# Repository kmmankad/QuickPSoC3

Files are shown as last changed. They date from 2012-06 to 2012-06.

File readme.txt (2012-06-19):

QuickPSoC3 V2
--------------

This is a quick-to-make development envrionment for the Cypress PSoC3 Platform.It is intended for students,hobbyists 
or anyone who wants a PSoC3 platform to play with,without paying a ton of money for it.

The goal is to have a home-etchable,cheap to put together,USB capable PSoC3 environment running with the least of hassle.

To know more about the PSoC3 platform - http://www.cypress.com/?id=2232

Board files are made in Eagle 6.2 LIGHT Edition.

This board:
-Uses the CY8C3866PVI-021/CY8C3246PVI-147 or any PSoC3 part in a 48pin SSOP package
-Has 26 GPIOs brought out to 0.1" headers.
-Uses the internal oscillator.
-Has a miniprog compatible header on the top right,for easy programming.
-Has a miniUSB connector,so can use a USB bootloader,for easier programming.
-Has extra long pads for soldering the PSoC,to make it easier for beginners to put together.
-The Mhz Crystal lines have not been routed out,but USB doesnt need an external crystal/resonator.
-Has smd passives of 0805 size,and the LEDs are 1206,but you can easily replace them with their through hole variants and get a fully through-hole board.
-Has an *Unregulated* voltage input which can be selected over USB's 5VDC.

I have successfully etched this using nothing but ordinary copier paper and a household iron,on some paper phenolic copper clad.So you dont require special techniques to etch it.

Updated 19-Jun-12:
Did away with some more components,to make this a quick-er board to put together.
Edited silkscreen at some places to make it more meaningful.

-kmmankad

http://kmmankad.blogspot.com

This work is licensed under a Creative Commons Attribution-ShareAlike 3.0 Unported License.

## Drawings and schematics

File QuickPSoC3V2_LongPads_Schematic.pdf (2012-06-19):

XRES - Reset Pushbutton | Mounting Holes

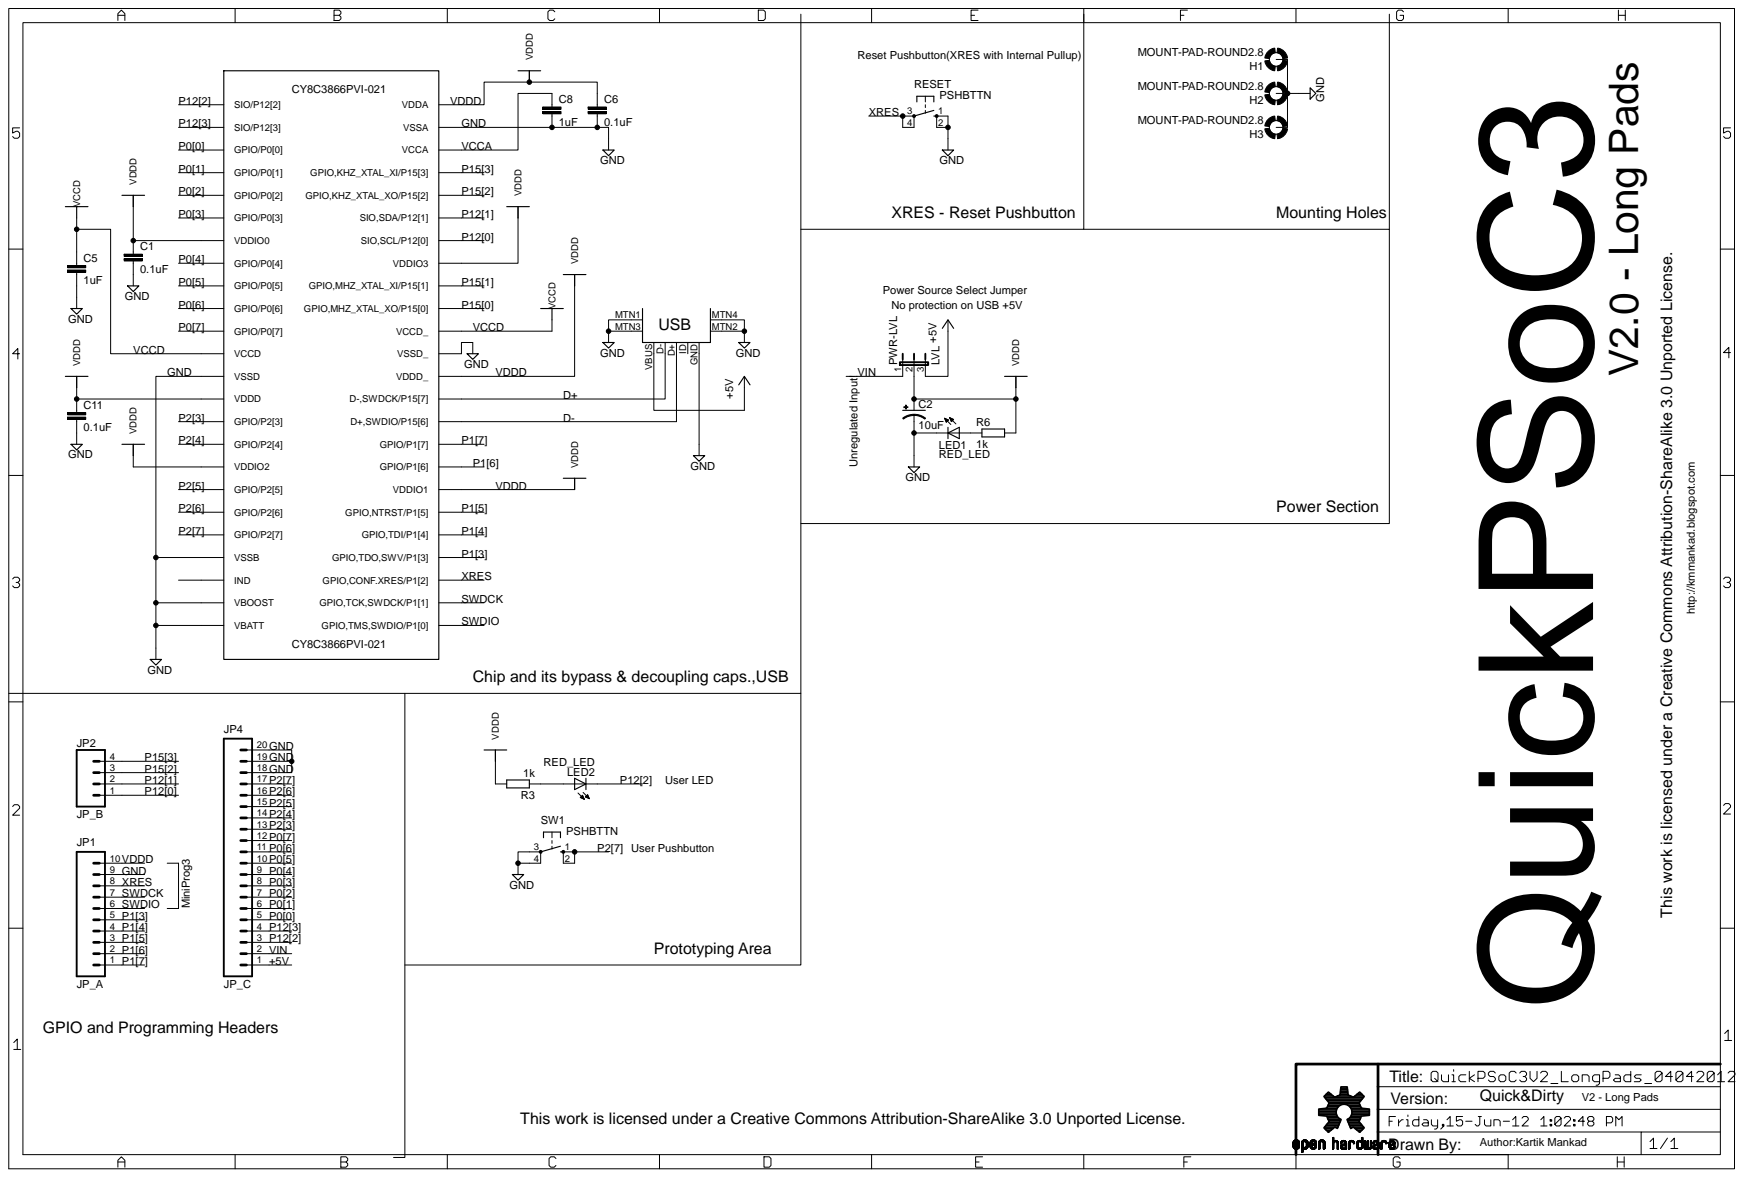
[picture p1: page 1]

Reset Pushbutton(XRES with Internal Pullup)

This work is licensed under a Creative Commons Attribution-ShareAlike 3.0 Unported License.

Power Source Select Jumper
No protection on USB +5V

http://kmmankad.blogspot.com

Chip and its bypass & decoupling caps.,USB

GPIO and Programming Headers

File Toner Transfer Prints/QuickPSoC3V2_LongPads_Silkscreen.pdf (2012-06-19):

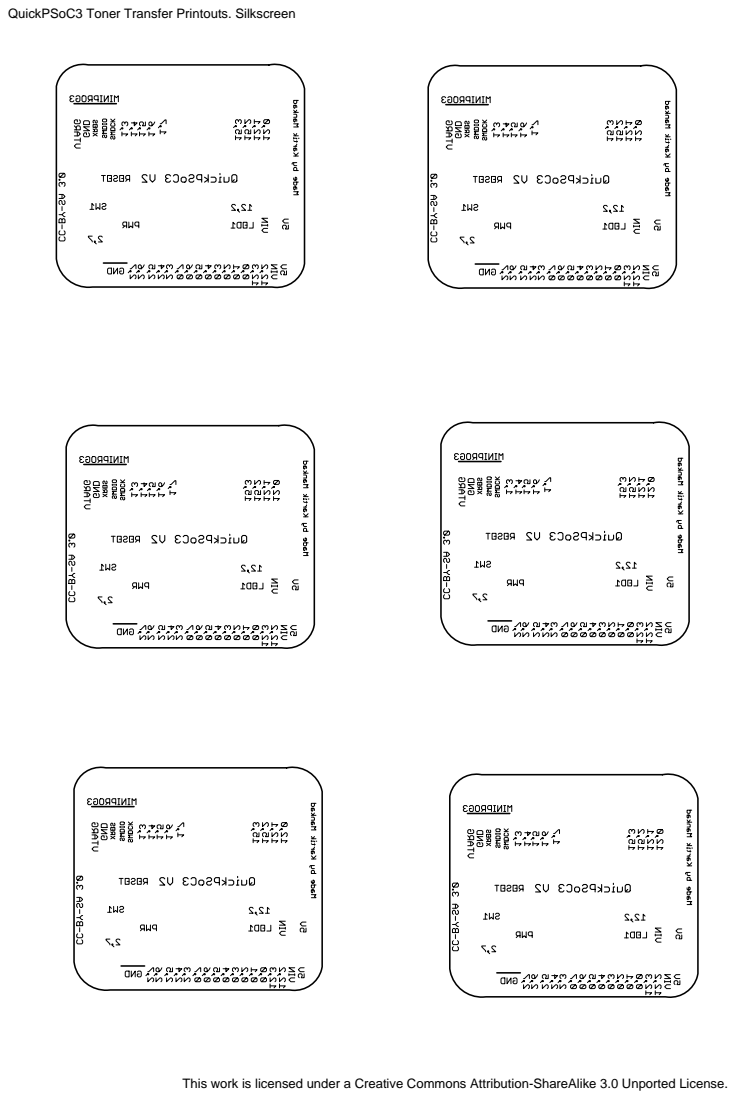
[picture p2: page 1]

QuickPSoC3 Toner Transfer Printouts. Silkscreen

This work is licensed under a Creative Commons Attribution-ShareAlike 3.0 Unported License.

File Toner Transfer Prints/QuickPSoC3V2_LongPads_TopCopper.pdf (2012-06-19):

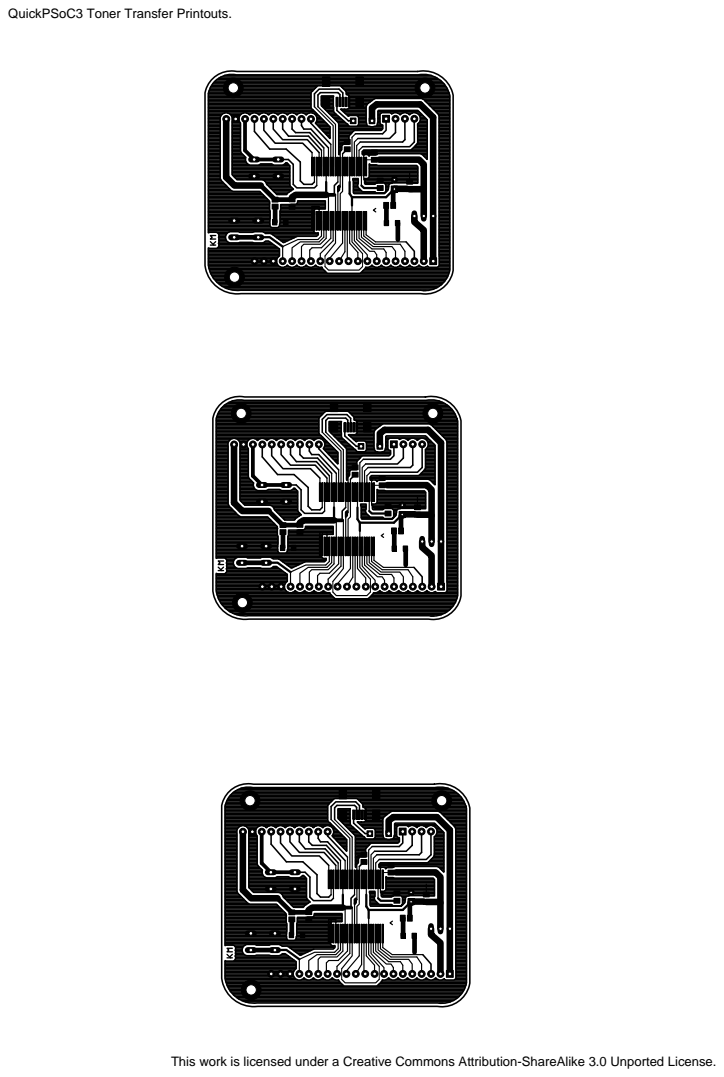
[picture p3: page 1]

QuickPSoC3 Toner Transfer Printouts.

This work is licensed under a Creative Commons Attribution-ShareAlike 3.0 Unported License.

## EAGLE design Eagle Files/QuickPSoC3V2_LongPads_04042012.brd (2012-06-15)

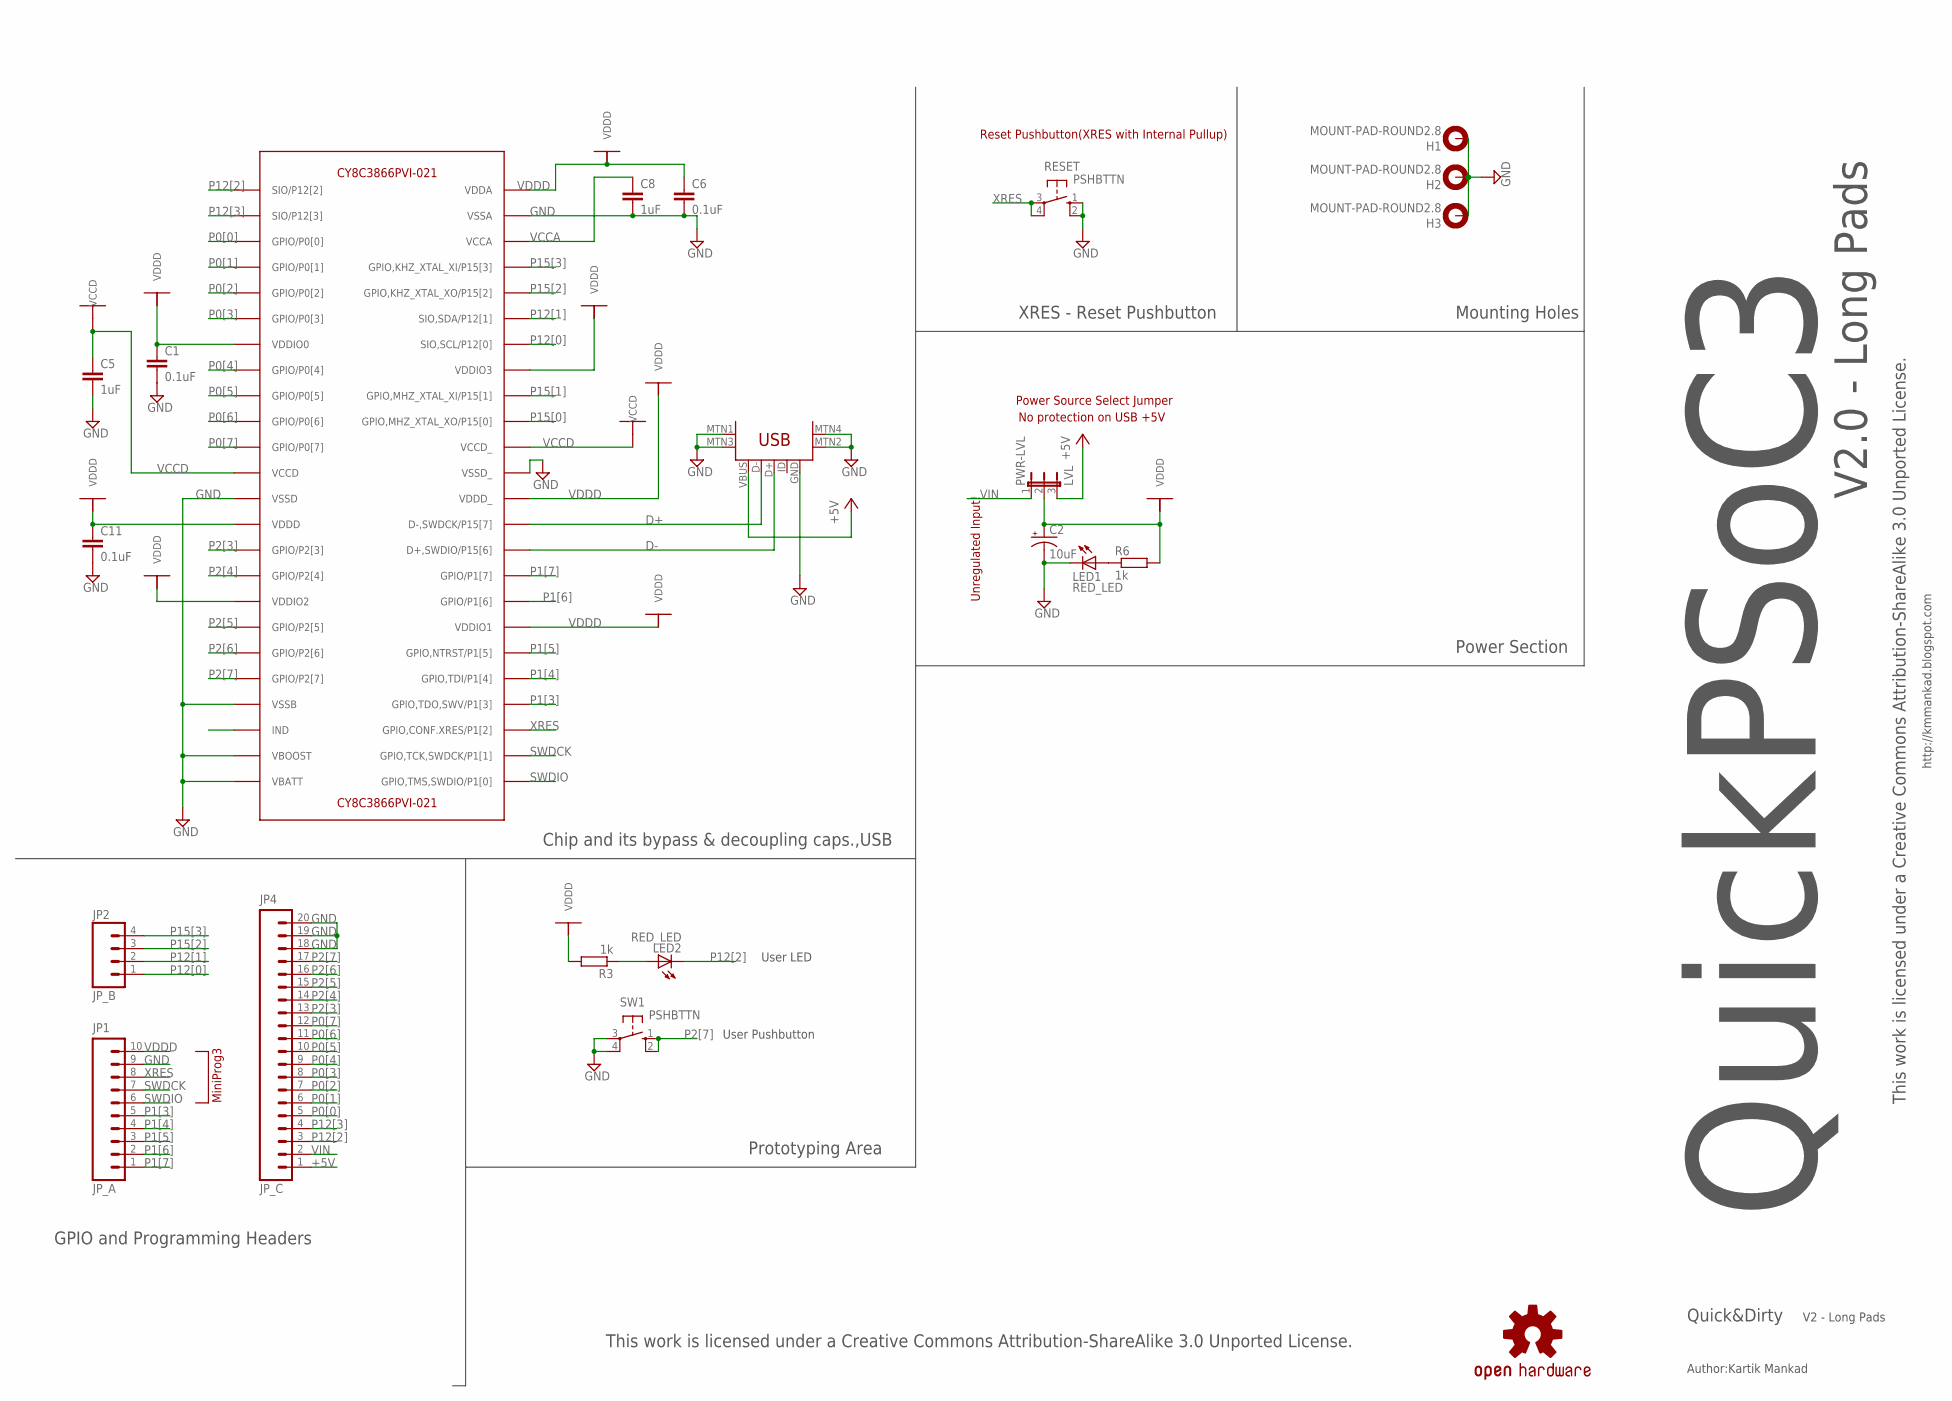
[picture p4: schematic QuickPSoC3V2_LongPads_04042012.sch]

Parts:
C1, C6, C11: 0.1uF; C0805K
C2: 10uF; CPOL-RADIAL-10UF-25V
C5, C8: 1uF; C0805K
H1, H2, H3: MOUNT-PAD-ROUND2.8; 2,8-PAD
JP1: JP_A; 1X10
JP2: JP_B; 1X04
JP4: JP_C; 1X20
LED1, LED2: RED_LED; LED-1206
PWR-LVL: LVL; JP2
R3, R6: 1k; M0805
RESET: PSHBTTN; B3F-10XX
SW1: PSHBTTN; B3F-10XX
U$1: CY8C3866PVI-021; SSOP48DL
U$2: OSHW-LOGOL; OSHW-LOGO-L
X1: USB-MINIB-5PIN; USB-MINIB

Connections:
+5V: JP4.1, PWR-LVL.3, X1.VBUS
D+: U$1.35 (D-,SWDCK/P15[7]), X1.D-
D-: U$1.34 (D+,SWDIO/P15[6]), X1.D+
GND: C1.2, C2.2 (-), C5.2, C6.2, C8.2, C11.2, H1.B2,8, H2.B2,8, H3.B2,8, JP1.9, JP4.18, JP4.19, JP4.20, LED1.C, RESET.1 (S), RESET.2 (S1), SW1.3, SW1.4 (P1), U$1.13 (VSSD), U$1.21 (VSSB), U$1.23 (VBOOST), U$1.24 (VBATT), U$1.37 (VSSD_), U$1.47 (VSSA), X1.GND, X1.MTN1 (MTN2), X1.MTN2 (MTN3), X1.MTN3 (MTN1), X1.MTN4
unnamed: LED1.A, R6.1
unnamed: LED2.A, R3.1
P0[0]: JP4.5, U$1.3 (GPIO/P0[0])
P0[1]: JP4.6, U$1.4 (GPIO/P0[1])
P0[2]: JP4.7, U$1.5 (GPIO/P0[2])
P0[3]: JP4.8, U$1.6 (GPIO/P0[3])
P0[4]: JP4.9, U$1.8 (GPIO/P0[4])
P0[5]: JP4.10, U$1.9 (GPIO/P0[5])
P0[6]: JP4.11, U$1.10 (GPIO/P0[6])
P0[7]: JP4.12, U$1.11 (GPIO/P0[7])
P1[3]: JP1.5, U$1.28 (GPIO,TDO,SWV/P1[3])
P1[4]: JP1.4, U$1.29 (GPIO,TDI/P1[4])
P1[5]: JP1.3, U$1.30 (GPIO,NTRST/P1[5])
P1[6]: JP1.2, U$1.32 (GPIO/P1[6])
P1[7]: JP1.1, U$1.33 (GPIO/P1[7])
P2[3]: JP4.13, U$1.15 (GPIO/P2[3])
P2[4]: JP4.14, U$1.16 (GPIO/P2[4])
P2[5]: JP4.15, U$1.18 (GPIO/P2[5])
P2[6]: JP4.16, U$1.19 (GPIO/P2[6])
P2[7]: JP4.17, SW1.1 (S), SW1.2 (S1), U$1.20 (GPIO/P2[7])
P12[0]: JP2.1, U$1.42 (SIO,SCL/P12[0])
P12[1]: JP2.2, U$1.43 (SIO,SDA/P12[1])
P12[2]: JP4.3, LED2.C, U$1.1 (SIO/P12[2])
P12[3]: JP4.4, U$1.2 (SIO/P12[3])
P15[0]: U$1.39 (GPIO,MHZ_XTAL_XO/P15[0])
P15[1]: U$1.40 (GPIO,MHZ_XTAL_XI/P15[1])
P15[2]: JP2.3, U$1.44 (GPIO,KHZ_XTAL_XO/P15[2])
P15[3]: JP2.4, U$1.45 (GPIO,KHZ_XTAL_XI/P15[3])
SWDCK: JP1.7, U$1.26 (GPIO,TCK,SWDCK/P1[1])
SWDIO: JP1.6, U$1.25 (GPIO,TMS,SWDIO/P1[0])
VCCA: C8.1, U$1.46 (VCCA)
VCCD: C5.1, U$1.12 (VCCD), U$1.38 (VCCD_)
VDDD: C1.1, C2.1 (+), C6.1, C11.1, JP1.10, PWR-LVL.2, R3.2, R6.2, U$1.7 (VDDIO0), U$1.14 (VDDD), U$1.17 (VDDIO2), U$1.31 (VDDIO1), U$1.36 (VDDD_), U$1.41 (VDDIO3), U$1.48 (VDDA)
VIN: JP4.2, PWR-LVL.1
XRES: JP1.8, RESET.3, RESET.4 (P1), U$1.27 (GPIO,CONF.XRES/P1[2])

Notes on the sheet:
Author:Kartik Mankad
This work is licensed under a Creative Commons Attribution-ShareAlike 3.0 Unported License.
Reset Pushbutton(XRES with Internal Pullup)
Quick&Dirty
MiniProg3
Unregulated Input!
Power Source Select Jumper
No protection on USB +5V
Chip and its bypass & decoupling caps.,USB
Power Section
XRES - Reset Pushbutton
Mounting Holes
Prototyping Area
GPIO and Programming Headers
User LED
User Pushbutton
QuickPSoC3
http://kmmankad.blogspot.com
V2 - Long Pads
V2.0 - Long Pads

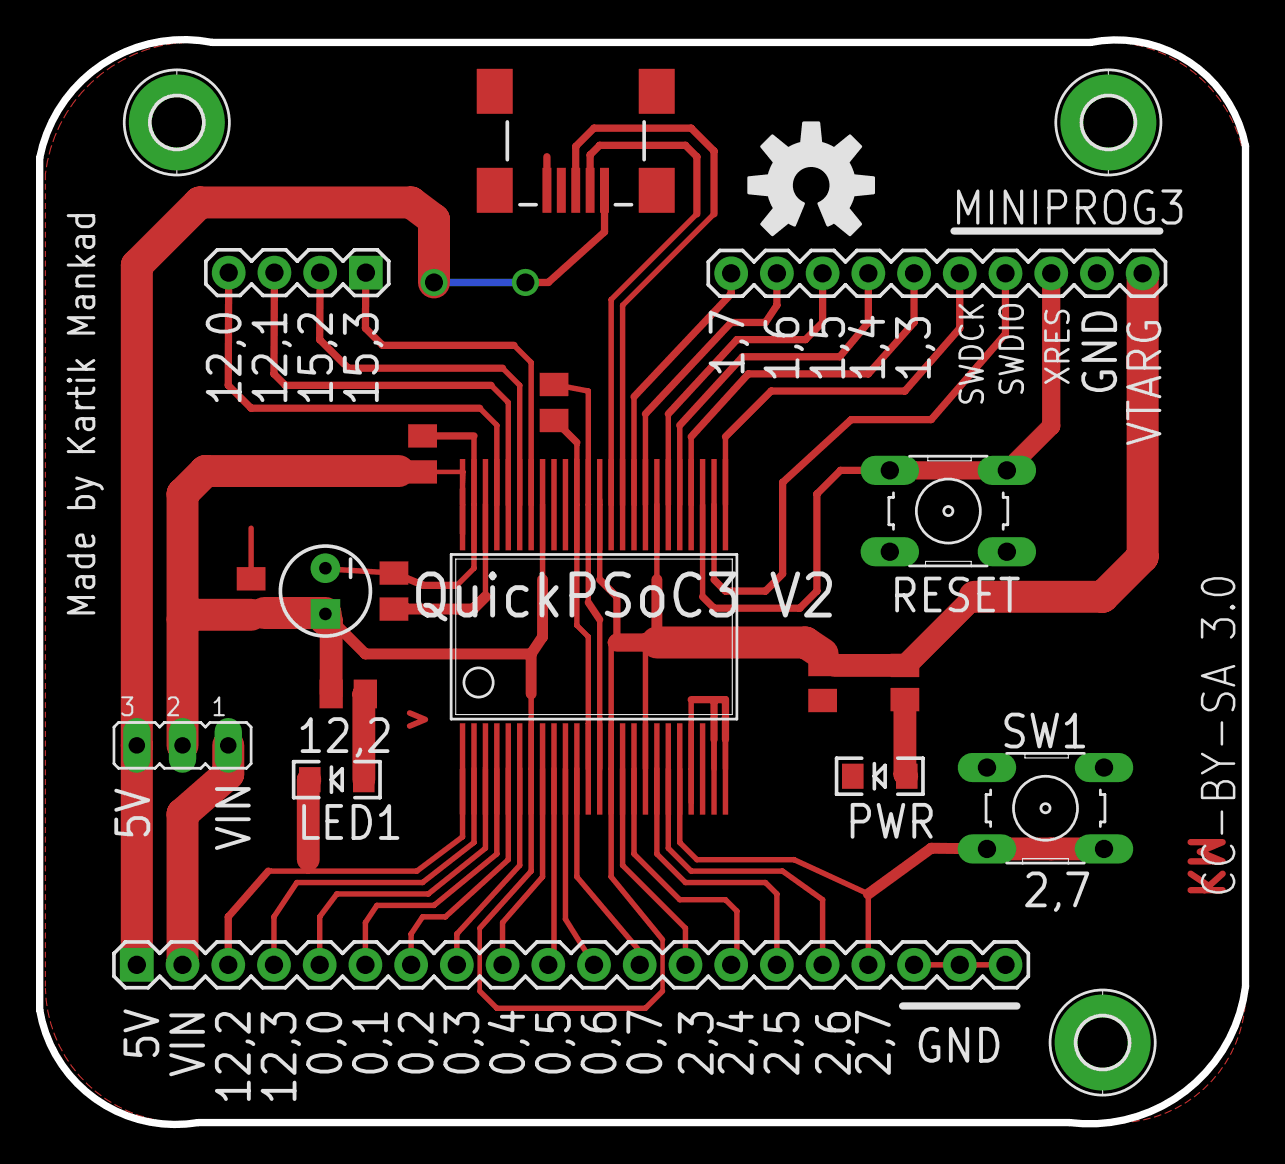
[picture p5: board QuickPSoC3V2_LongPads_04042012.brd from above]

Board: 2 copper layers, 67.0 x 60.3 mm, 23 parts (0 on the bottom side), 37 nets.

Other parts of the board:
U$3: LOGO

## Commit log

2012-04-08 First commit.
    [QuickPSoC3V2_LongPads_04042012.brd, QuickPSoC3V2_LongPads_04042012.sch]
2012-04-08 updated basic info about the board
2012-04-08 Changed directory structure,titled toner-transfer printouts.
    [QuickPSoC3V2_LongPads_04042012.brd, QuickPSoC3V2_LongPads_04042012.sch]
2012-04-08 Fixed the silkscreen text for SW1.
2012-06-15 Removed the 22ohm resistors on the USB lines,since it works just fine without them. Removed 10uF cap on USB +5V line. Added MiniProg3 insertion indication on silkscreen.
    Edited gitignore to ignore *.s#* and *.b#* files.
    [QuickPSoC3V2_LongPads_04042012.brd, QuickPSoC3V2_LongPads_04042012.sch]

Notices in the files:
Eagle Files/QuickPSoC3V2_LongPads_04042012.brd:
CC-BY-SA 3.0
